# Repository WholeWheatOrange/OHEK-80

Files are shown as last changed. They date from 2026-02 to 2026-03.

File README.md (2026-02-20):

# OHEK-80
An analog hall effect keyboard using [Void Switches](https://github.com/riskable/void_switch) in the traditional 87-key tenkeyless layout.

# Roadmap
## Under Development
- PCB
## Planned Features
- Analog input
- Adjustable actuation point
- Rapid Trigger
- SOCD
- That Stupid Strap Attachment That Is A Trend In Hall Effect Keyboards

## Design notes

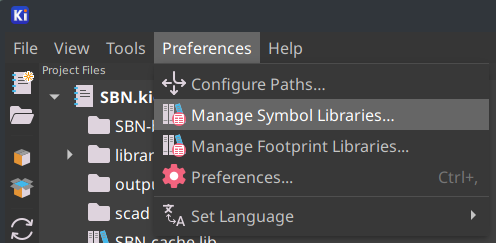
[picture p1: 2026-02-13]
kicad/void_switch_kicad/assets/images/prefs_symbols.png

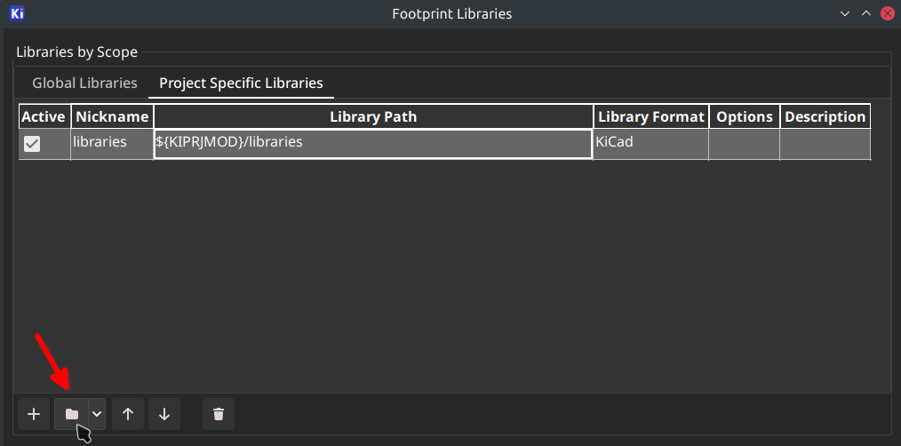
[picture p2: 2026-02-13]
kicad/void_switch_kicad/assets/images/add_footprint_path1.png

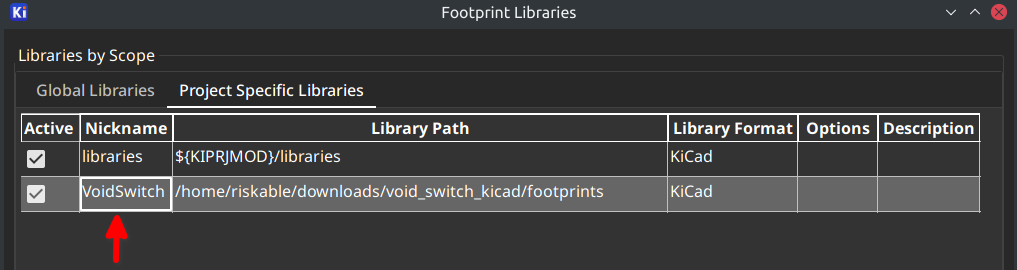
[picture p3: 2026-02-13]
kicad/void_switch_kicad/assets/images/add_footprint_path3.png

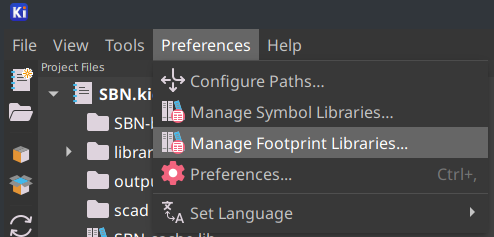
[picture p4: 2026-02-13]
kicad/void_switch_kicad/assets/images/prefs_footprints.png

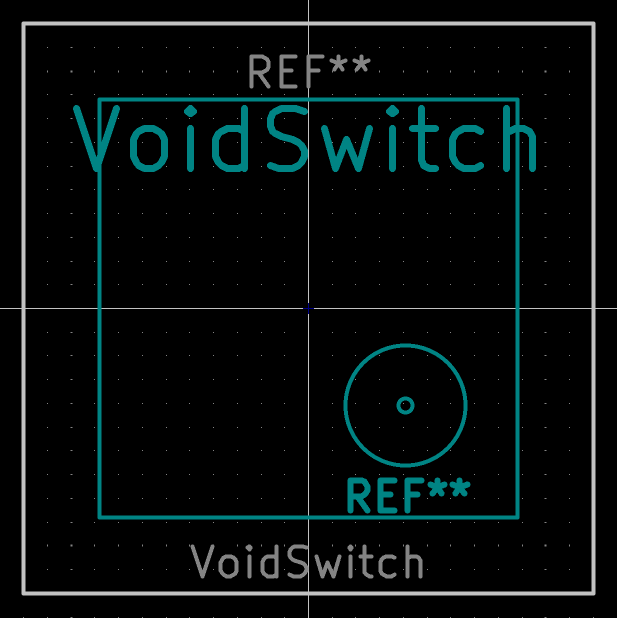
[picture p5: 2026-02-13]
kicad/void_switch_kicad/assets/images/voidswitch_footprint.png

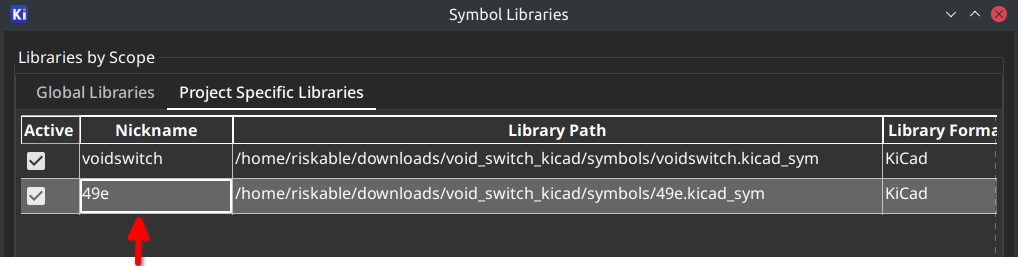
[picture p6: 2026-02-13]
kicad/void_switch_kicad/assets/images/add_symbols1.png

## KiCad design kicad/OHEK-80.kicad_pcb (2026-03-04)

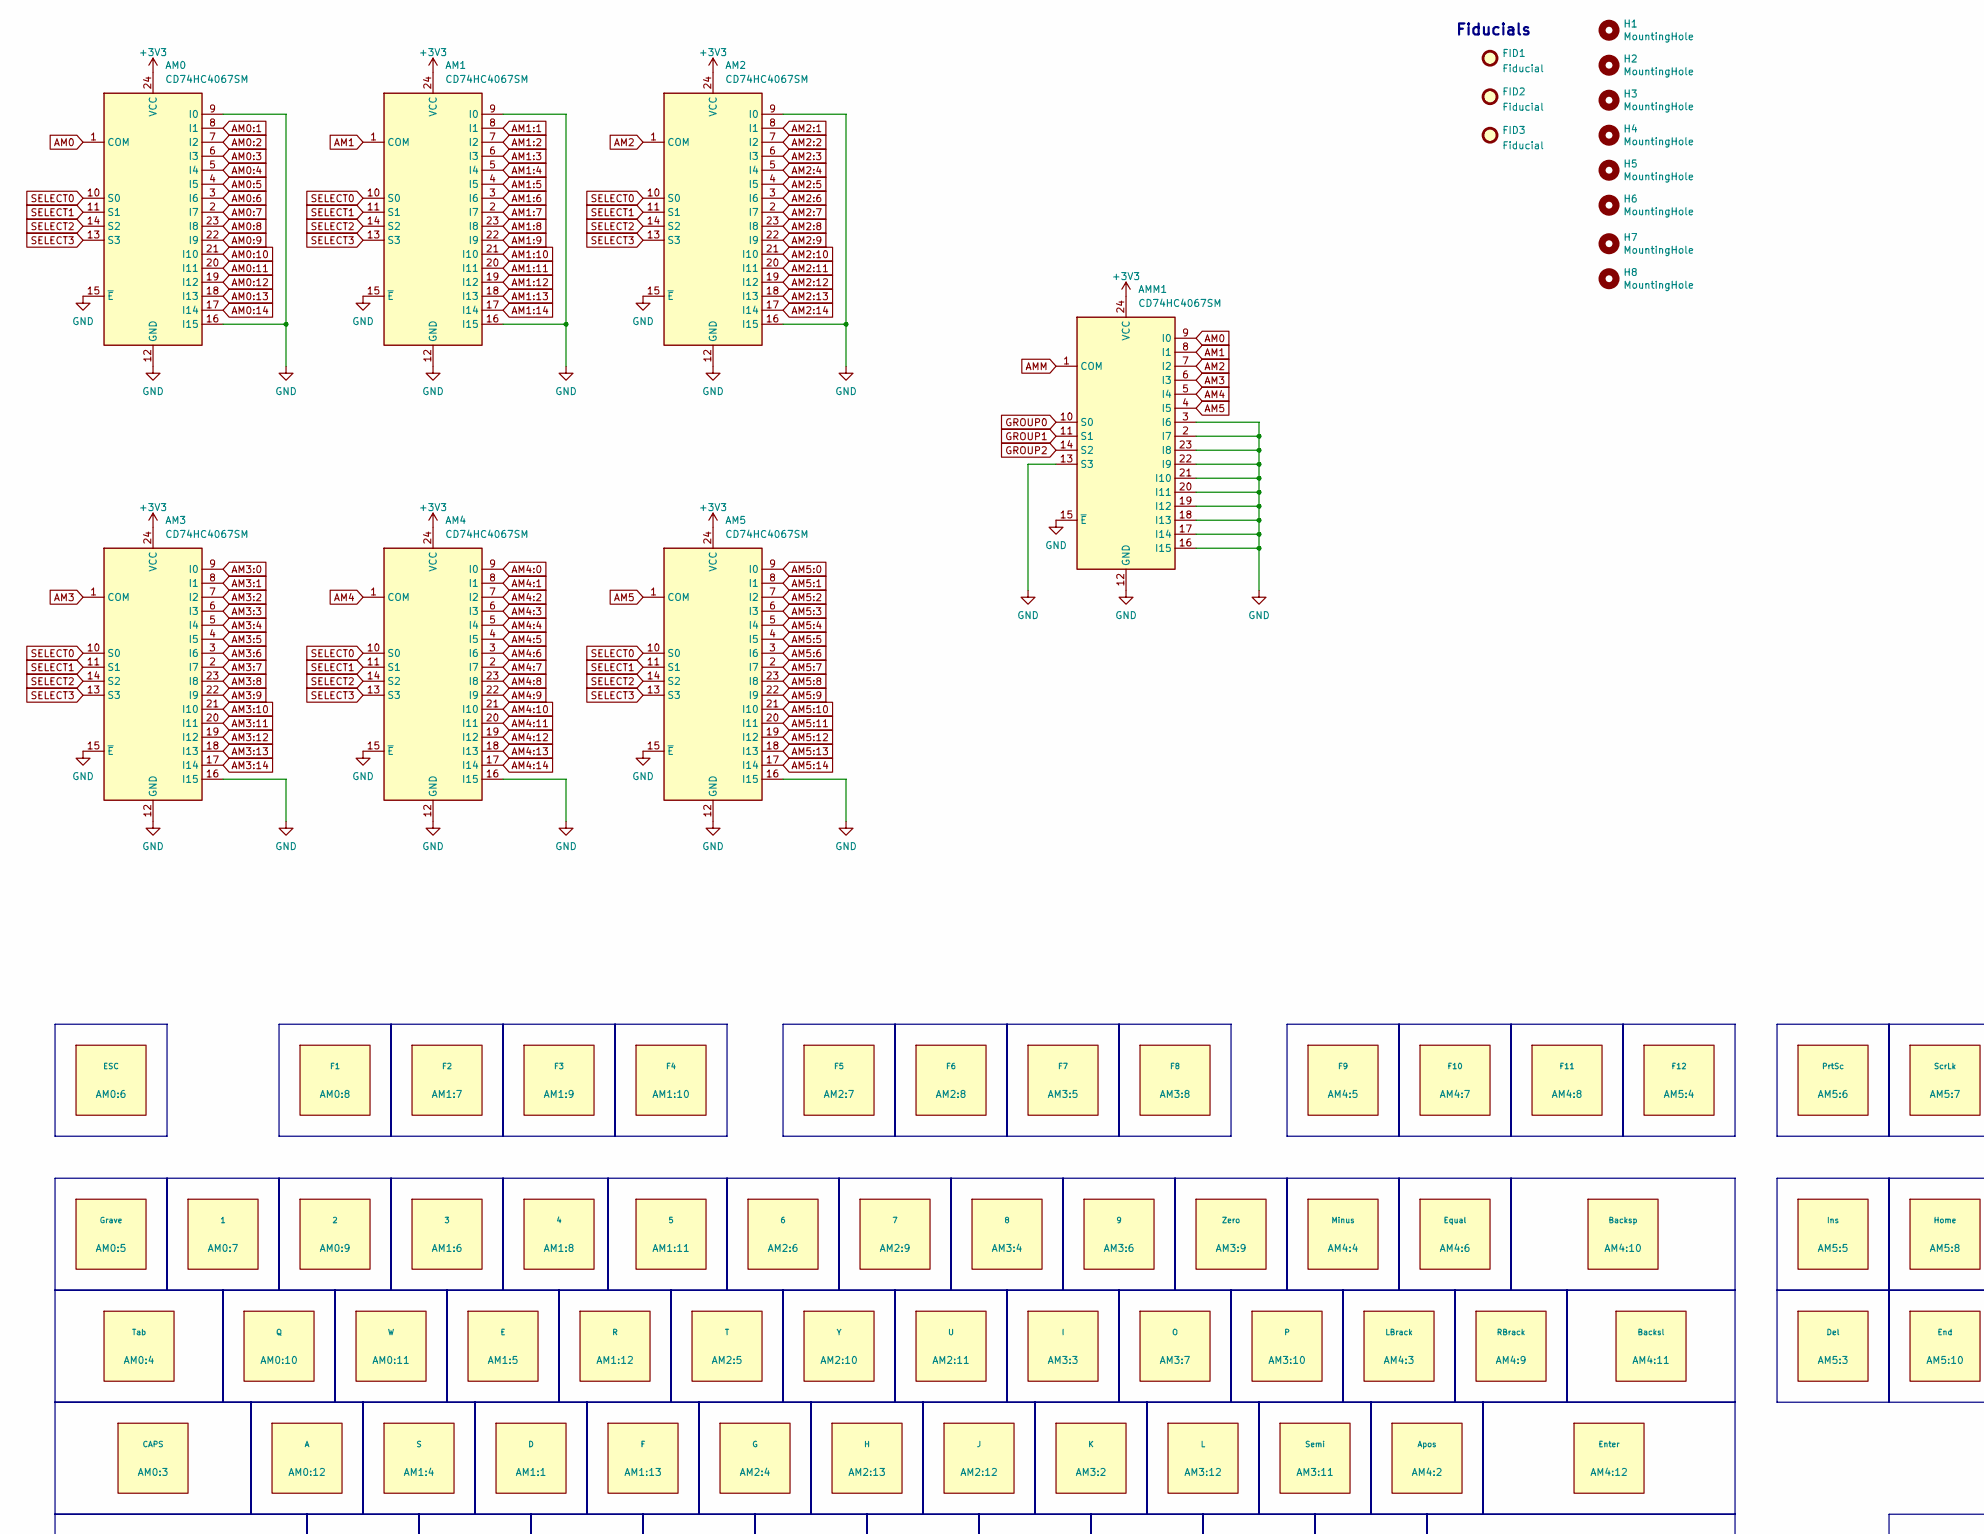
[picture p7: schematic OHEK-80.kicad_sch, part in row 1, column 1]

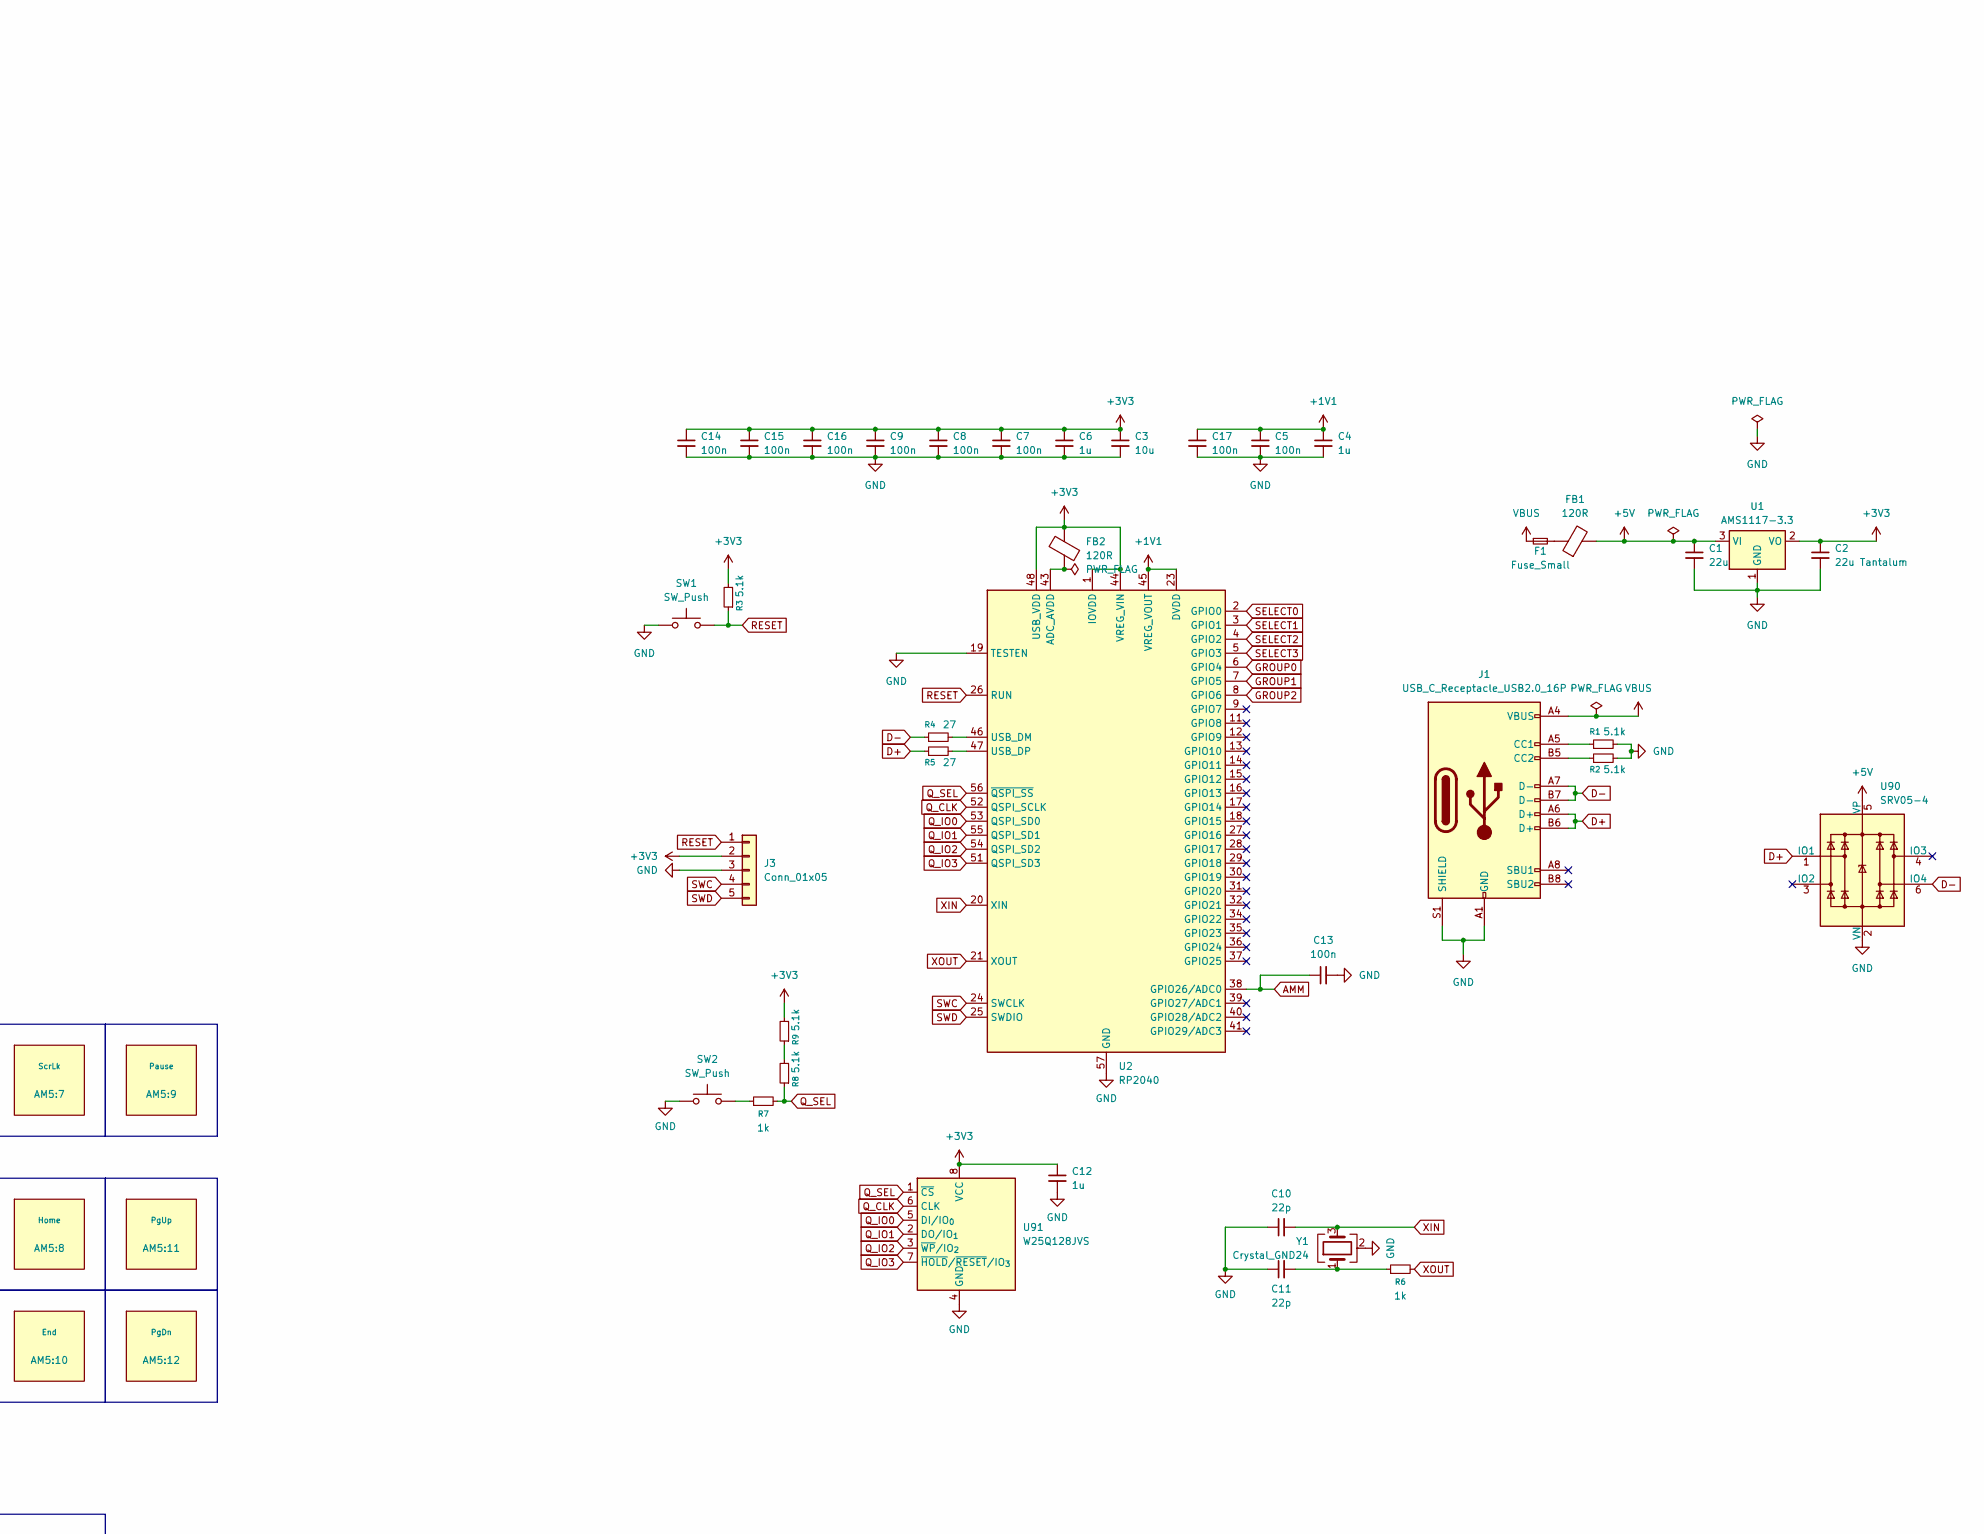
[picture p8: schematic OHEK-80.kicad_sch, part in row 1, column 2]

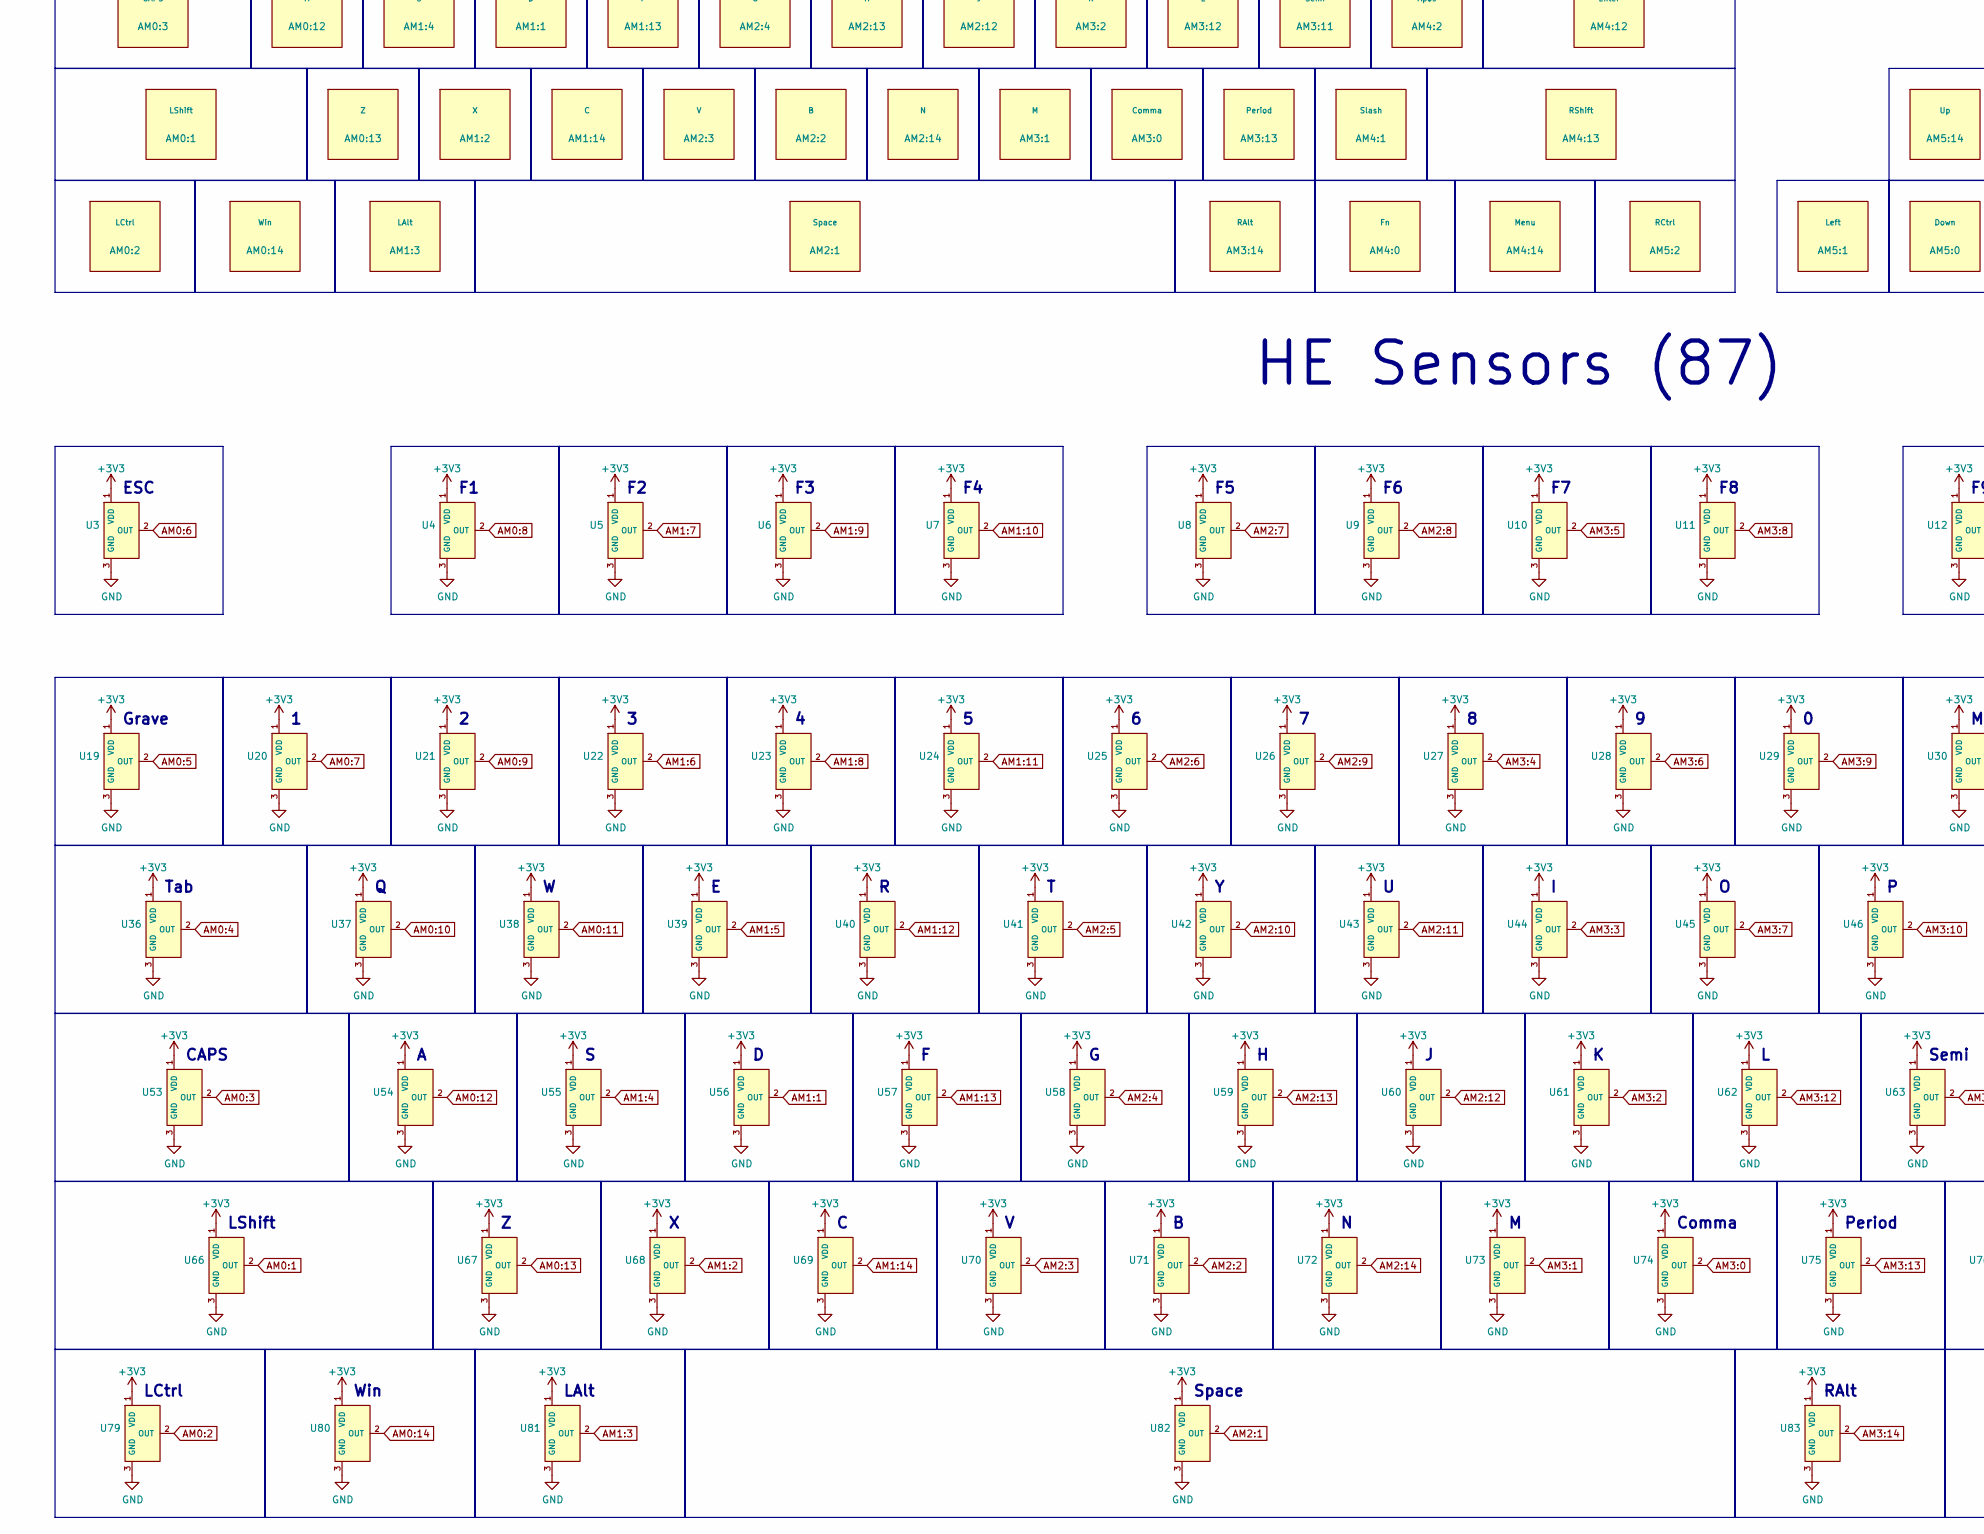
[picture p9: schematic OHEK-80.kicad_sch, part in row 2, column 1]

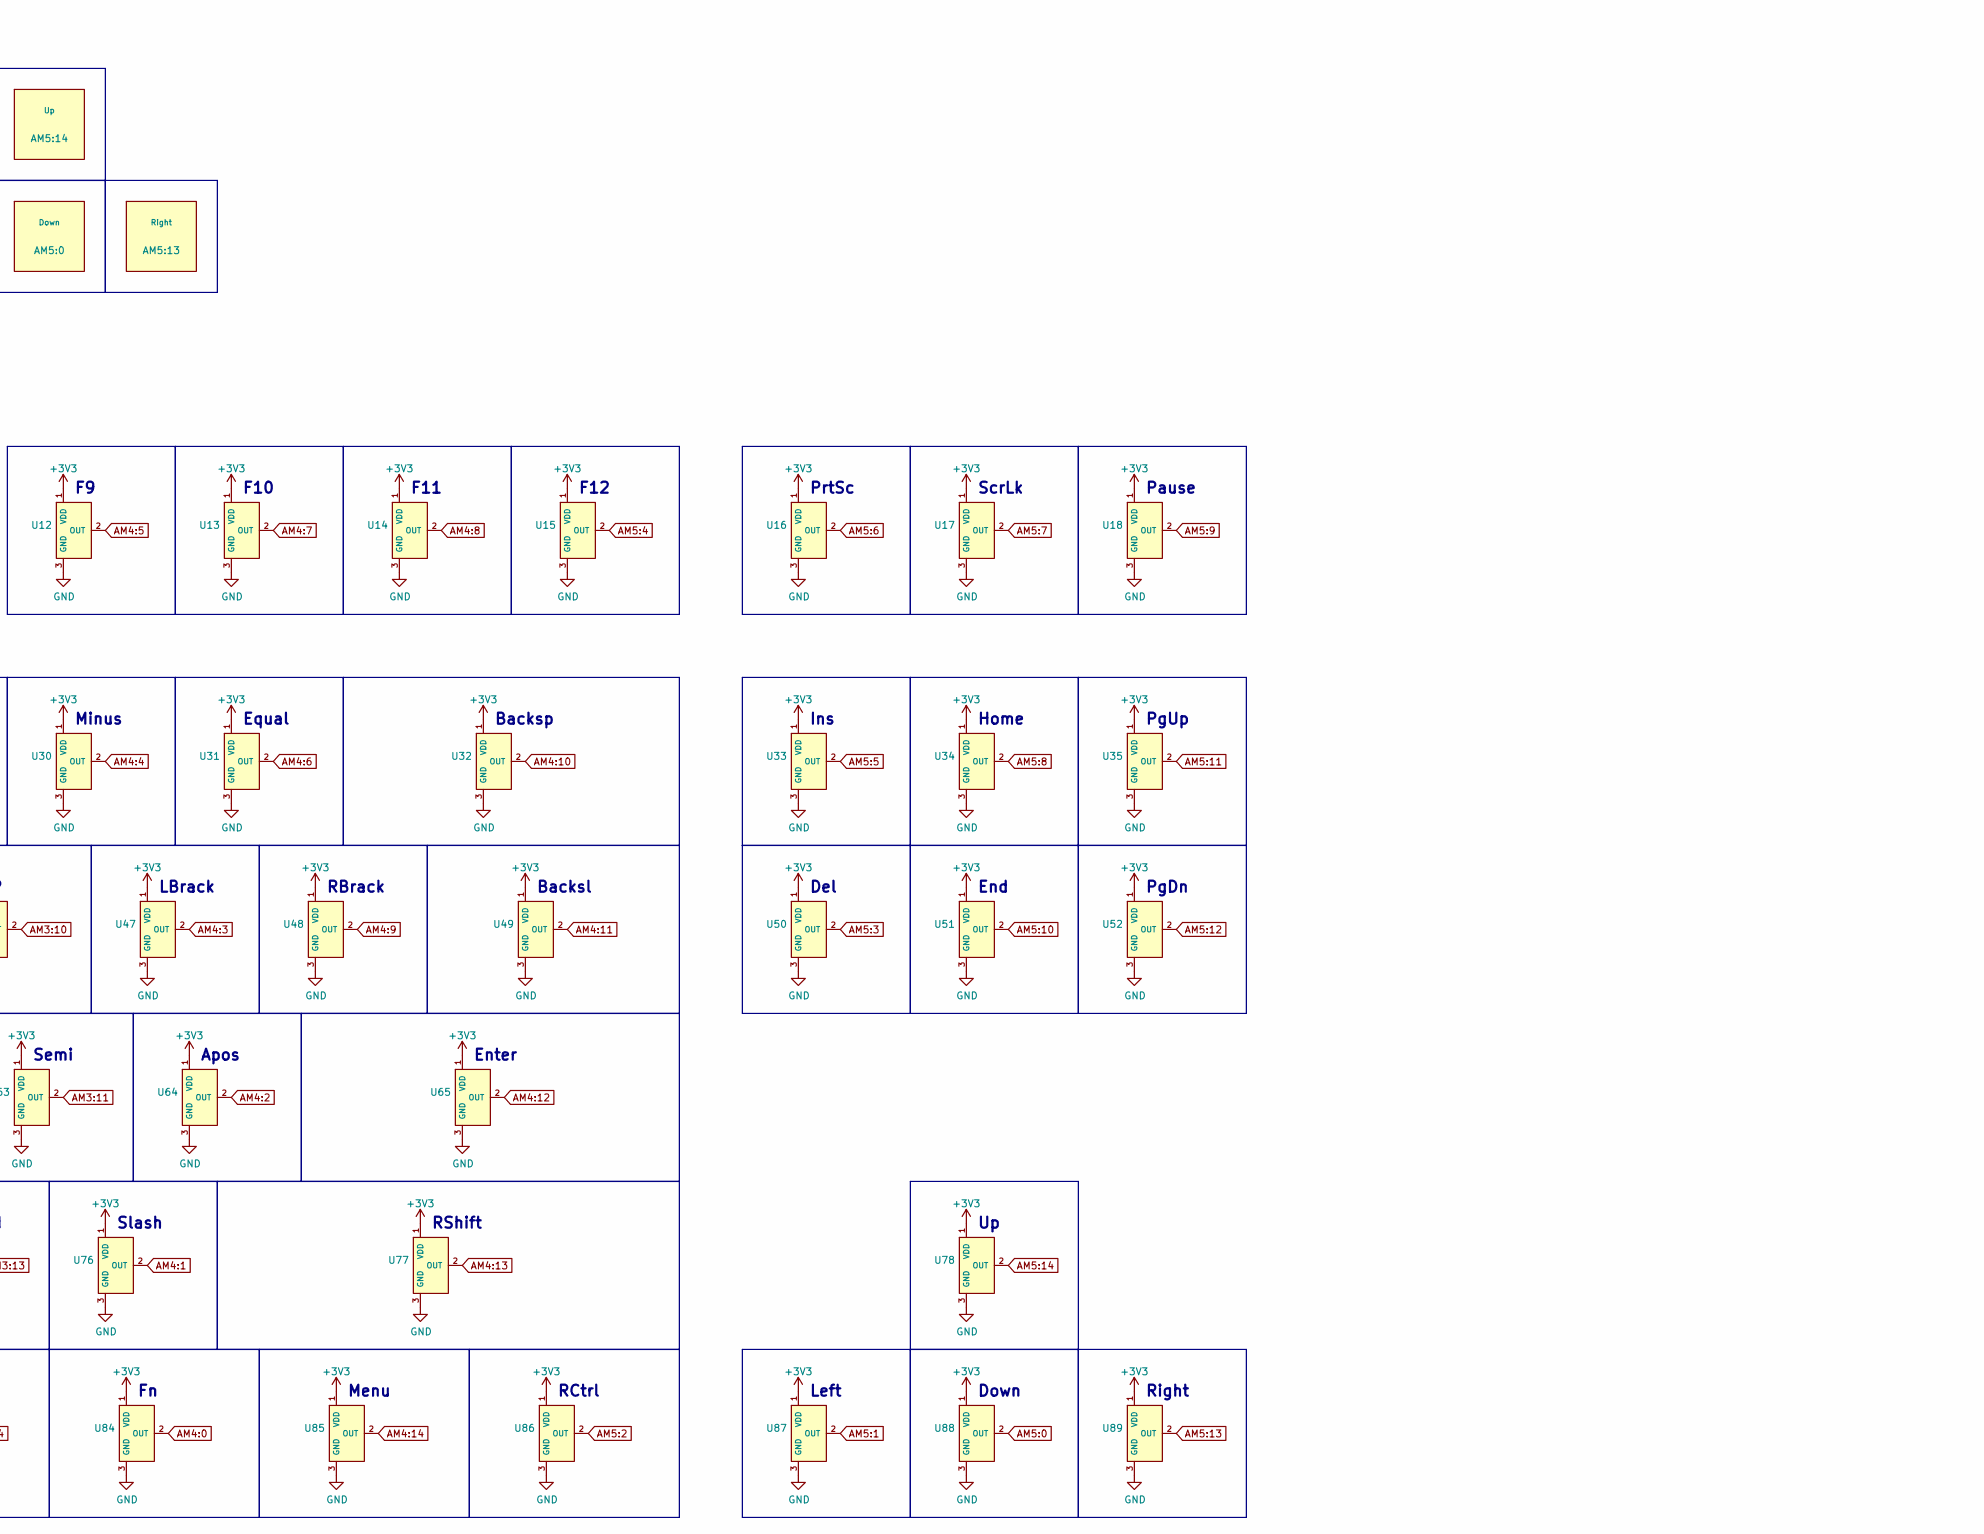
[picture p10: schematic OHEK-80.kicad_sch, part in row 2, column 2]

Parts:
AM0, AM1, AM2, AM3, AM4, AM5: CD74HC4067SM; SSOP-24_5.3x8.2mm_P0.65mm; LCSC C98457
AM0:1: LShift; VoidSwitch_2.25u_SMD
AM0:2: LCtrl; VoidSwitch_1.25u_SMD
AM0:3: CAPS; VoidSwitch_1.75u_SMD
AM0:4: Tab; VoidSwitch_1.5u_SMD
AM0:5: Grave; VoidSwitch_1u_SMD
AM0:6: ESC; VoidSwitch_1u_SMD
AM0:7: 1; VoidSwitch_1u_SMD
AM0:8: F1; VoidSwitch_1u_SMD
AM0:9: 2; VoidSwitch_1u_SMD
AM0:10: Q; VoidSwitch_1u_SMD
AM0:11: W; VoidSwitch_1u_SMD
AM0:12: A; VoidSwitch_1u_SMD
AM0:13: Z; VoidSwitch_1u_SMD
AM0:14: Win; VoidSwitch_1.25u_SMD
AM1:1: D; VoidSwitch_1u_SMD
AM1:2: X; VoidSwitch_1u_SMD
AM1:3: LAlt; VoidSwitch_1.25u_SMD
AM1:4: S; VoidSwitch_1u_SMD
AM1:5: E; VoidSwitch_1u_SMD
AM1:6: 3; VoidSwitch_1u_SMD
AM1:7: F2; VoidSwitch_1u_SMD
AM1:8: 4; VoidSwitch_1u_SMD
AM1:9: F3; VoidSwitch_1u_SMD
AM1:10: F4; VoidSwitch_1u_SMD
AM1:11: 5; VoidSwitch_1u_SMD
AM1:12: R; VoidSwitch_1u_SMD
AM1:13: F; VoidSwitch_1u_SMD
AM1:14: C; VoidSwitch_1u_SMD
AM2:1: Space; VoidSwitch_6.25u_SMD
AM2:2: B; VoidSwitch_1u_SMD
AM2:3: V; VoidSwitch_1u_SMD
AM2:4: G; VoidSwitch_1u_SMD
AM2:5: T; VoidSwitch_1u_SMD
AM2:6: 6; VoidSwitch_1u_SMD
AM2:7: F5; VoidSwitch_1u_SMD
AM2:8: F6; VoidSwitch_1u_SMD
AM2:9: 7; VoidSwitch_1u_SMD
AM2:10: Y; VoidSwitch_1u_SMD
AM2:11: U; VoidSwitch_1u_SMD
AM2:12: J; VoidSwitch_1u_SMD
AM2:13: H; VoidSwitch_1u_SMD
AM2:14: N; VoidSwitch_1u_SMD
AM3:0: Comma; VoidSwitch_1u_SMD
AM3:1: M; VoidSwitch_1u_SMD
AM3:2: K; VoidSwitch_1u_SMD
AM3:3: I; VoidSwitch_1u_SMD
AM3:4: 8; VoidSwitch_1u_SMD
AM3:5: F7; VoidSwitch_1u_SMD
AM3:6: 9; VoidSwitch_1u_SMD
AM3:7: O; VoidSwitch_1u_SMD
AM3:8: F8; VoidSwitch_1u_SMD
AM3:9: Zero; VoidSwitch_1u_SMD
AM3:10: P; VoidSwitch_1u_SMD
AM3:11: Semi; VoidSwitch_1u_SMD
AM3:12: L; VoidSwitch_1u_SMD
AM3:13: Period; VoidSwitch_1u_SMD
AM3:14: RAlt; VoidSwitch_1.25u_SMD
AM4:0: Fn; VoidSwitch_1.25u_SMD
AM4:1: Slash; VoidSwitch_1u_SMD
AM4:2: Apos; VoidSwitch_1u_SMD
AM4:3: LBrack; VoidSwitch_1u_SMD
AM4:4: Minus; VoidSwitch_1u_SMD
AM4:5: F9; VoidSwitch_1u_SMD
AM4:6: Equal; VoidSwitch_1u_SMD
AM4:7: F10; VoidSwitch_1u_SMD
AM4:8: F11; VoidSwitch_1u_SMD
AM4:9: RBrack; VoidSwitch_1u_SMD
AM4:10: Backsp; VoidSwitch_2u_SMD
AM4:11: Backsl; VoidSwitch_1.5u_SMD
AM4:12: Enter; VoidSwitch_2.25u_SMD
AM4:13: RShift; VoidSwitch_2.75u_SMD
AM4:14: Menu; VoidSwitch_1.25u_SMD
AM5:0: Down; VoidSwitch_1u_SMD
AM5:1: Left; VoidSwitch_1u_SMD
AM5:2: RCtrl; VoidSwitch_1.25u_SMD
AM5:3: Del; VoidSwitch_1u_SMD
AM5:4: F12; VoidSwitch_1u_SMD
AM5:5: Ins; VoidSwitch_1u_SMD
AM5:6: PrtSc; VoidSwitch_1u_SMD
AM5:7: ScrLk; VoidSwitch_1u_SMD
AM5:8: Home; VoidSwitch_1u_SMD
AM5:9: Pause; VoidSwitch_1u_SMD
AM5:10: End; VoidSwitch_1u_SMD
AM5:11: PgUp; VoidSwitch_1u_SMD
AM5:12: PgDn; VoidSwitch_1u_SMD
AM5:13: Right; VoidSwitch_1u_SMD
AM5:14: Up; VoidSwitch_1u_SMD
AMM1: CD74HC4067SM; SSOP-24_5.3x8.2mm_P0.65mm; LCSC C98457
C1: 22u; C_0805_2012Metric
C2: 22u Tantalum; C_0805_2012Metric; LCSC C1954754
C3: 10u; C_0805_2012Metric
C4, C6, C12: 1u; C_0805_2012Metric
C5, C7, C8, C9, C13, C14, C15, C16, C17: 100n; C_0805_2012Metric
C10, C11: 22p; C_0805_2012Metric
F1: Fuse_Small; Fuse_1206_3216Metric; LCSC C49318386
FB1, FB2: 120R; L_0805_2012Metric; LCSC C79382
FID1, FID2, FID3: Fiducial; Fiducial_1mm_Mask2mm
H1, H2, H3, H4, H5, H6, H7, H8: MountingHole; MountingHole_3.2mm_M3_Pad
J1: USB_C_Receptacle_USB2.0_16P; USB_C_Receptacle_HRO_TYPE-C-31-M-12; LCSC C165948
J3: Conn_01x05; JST_PH_S5B-PH-K_1x05_P2.00mm_Horizontal; LCSC C157923
R1, R2, R3, R8, R9: 5.1k; R_0805_2012Metric
R4, R5: 27; R_0805_2012Metric
R6, R7: 1k; R_0805_2012Metric
SW1, SW2: SW_Push; SW_SPST_TL3342; LCSC C318884
U1: AMS1117-3.3; SOT-223-3_TabPin2; LCSC C6186
U2: RP2040; QFN-56-1EP_7x7mm_P0.4mm_EP3.2x3.2mm; LCSC C2040
U3, U4, U5, U6, U7, U8, U9, U10, U11, U12, U13, U14, U15, U16, U17, U18, U19, U20, U21, U22, U23, U24, U25, U26, U27, U28, U29, U30, U31, U32, U33, U34, U35, U36, U37, U38, U39, U40, U41, U42, U43, U44, U45, U46, U47, U48, U49, U50, U51, U52, U53, U54, U55, U56, U57, U58, U59, U60, U61, U62, U63, U64, U65, U66, U67, U68, U69, U70, U71, U72, U73, U74, U75, U76, U77, U78, U79, U80, U81, U82, U83, U84, U85, U86, U87, U88, U89: GH39FKSW; SOT-23; MPN GH39FKSW; LCSC Part C266230
U90: SRV05-4; SOT-23-6; LCSC C7420376
U91: W25Q128JVS; SOIC-8_5.3x5.3mm_P1.27mm; LCSC C97521
Y1: Crystal_GND24; Crystal_SMD_3225-4Pin_3.2x2.5mm; LCSC C20625731

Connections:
+1V1: C4.1, C5.1, C17.1, U2.23 (DVDD), U2.45 (VREG_VOUT), U2.50 (DVDD)
+3V3: AM0.24 (VCC), AM1.24 (VCC), AM2.24 (VCC), AM3.24 (VCC), AM4.24 (VCC), AM5.24 (VCC), AMM1.24 (VCC), C2.1, C3.1, C6.1, C7.1, C8.1, C9.1, C12.1, C14.1, C15.1, C16.1, FB2.2, J3.2, R3.2, R9.2, U1.2 (VO), U2.1 (IOVDD), U2.10 (IOVDD), U2.22 (IOVDD), U2.33 (IOVDD), U2.42 (IOVDD), U2.44 (VREG_VIN), U2.48 (USB_VDD), U2.49 (IOVDD), U3.1 (VDD), U4.1 (VDD), U5.1 (VDD), U6.1 (VDD), U7.1 (VDD), U8.1 (VDD), U9.1 (VDD), U10.1 (VDD), U11.1 (VDD), U12.1 (VDD), U13.1 (VDD), U14.1 (VDD), U15.1 (VDD), U16.1 (VDD), U17.1 (VDD), U18.1 (VDD), U19.1 (VDD), U20.1 (VDD), U21.1 (VDD), U22.1 (VDD), U23.1 (VDD), U24.1 (VDD), U25.1 (VDD), U26.1 (VDD), U27.1 (VDD), U28.1 (VDD), U29.1 (VDD), U30.1 (VDD), U31.1 (VDD), U32.1 (VDD), U33.1 (VDD), U34.1 (VDD), U35.1 (VDD), U36.1 (VDD), U37.1 (VDD), U38.1 (VDD), U39.1 (VDD), U40.1 (VDD), U41.1 (VDD), U42.1 (VDD), U43.1 (VDD), U44.1 (VDD), U45.1 (VDD), U46.1 (VDD), U47.1 (VDD), U48.1 (VDD), U49.1 (VDD), U50.1 (VDD), U51.1 (VDD), U52.1 (VDD), U53.1 (VDD), U54.1 (VDD), U55.1 (VDD), U56.1 (VDD), U57.1 (VDD), U58.1 (VDD), U59.1 (VDD), U60.1 (VDD), U61.1 (VDD), U62.1 (VDD), U63.1 (VDD), U64.1 (VDD), U65.1 (VDD), U66.1 (VDD), U67.1 (VDD), U68.1 (VDD), U69.1 (VDD), U70.1 (VDD), U71.1 (VDD), U72.1 (VDD), U73.1 (VDD), U74.1 (VDD), U75.1 (VDD), U76.1 (VDD), U77.1 (VDD), U78.1 (VDD), U79.1 (VDD), U80.1 (VDD), U81.1 (VDD), U82.1 (VDD), U83.1 (VDD), U84.1 (VDD), U85.1 (VDD), U86.1 (VDD), U87.1 (VDD), U88.1 (VDD), U89.1 (VDD), U91.8 (VCC)
+5V: C1.1, FB1.2, U1.3 (VI), U90.5 (VP)
AM0: AM0.1 (COM), AMM1.9 (I0)
AM0:1: AM0.8 (I1), U66.2 (OUT)
AM0:2: AM0.7 (I2), U79.2 (OUT)
AM0:3: AM0.6 (I3), U53.2 (OUT)
AM0:4: AM0.5 (I4), U36.2 (OUT)
AM0:5: AM0.4 (I5), U19.2 (OUT)
AM0:6: AM0.3 (I6), U3.2 (OUT)
AM0:7: AM0.2 (I7), U20.2 (OUT)
AM0:8: AM0.23 (I8), U4.2 (OUT)
AM0:9: AM0.22 (I9), U21.2 (OUT)
AM0:10: AM0.21 (I10), U37.2 (OUT)
AM0:11: AM0.20 (I11), U38.2 (OUT)
AM0:12: AM0.19 (I12), U54.2 (OUT)
AM0:13: AM0.18 (I13), U67.2 (OUT)
AM0:14: AM0.17 (I14), U80.2 (OUT)
AM1: AM1.1 (COM), AMM1.8 (I1)
AM1:1: AM1.8 (I1), U56.2 (OUT)
AM1:2: AM1.7 (I2), U68.2 (OUT)
AM1:3: AM1.6 (I3), U81.2 (OUT)
AM1:4: AM1.5 (I4), U55.2 (OUT)
AM1:5: AM1.4 (I5), U39.2 (OUT)
AM1:6: AM1.3 (I6), U22.2 (OUT)
AM1:7: AM1.2 (I7), U5.2 (OUT)
AM1:8: AM1.23 (I8), U23.2 (OUT)
AM1:9: AM1.22 (I9), U6.2 (OUT)
AM1:10: AM1.21 (I10), U7.2 (OUT)
AM1:11: AM1.20 (I11), U24.2 (OUT)
AM1:12: AM1.19 (I12), U40.2 (OUT)
AM1:13: AM1.18 (I13), U57.2 (OUT)
AM1:14: AM1.17 (I14), U69.2 (OUT)
AM2: AM2.1 (COM), AMM1.7 (I2)
AM2:1: AM2.8 (I1), U82.2 (OUT)
AM2:2: AM2.7 (I2), U71.2 (OUT)
AM2:3: AM2.6 (I3), U70.2 (OUT)
AM2:4: AM2.5 (I4), U58.2 (OUT)
AM2:5: AM2.4 (I5), U41.2 (OUT)
AM2:6: AM2.3 (I6), U25.2 (OUT)
AM2:7: AM2.2 (I7), U8.2 (OUT)
AM2:8: AM2.23 (I8), U9.2 (OUT)
AM2:9: AM2.22 (I9), U26.2 (OUT)
AM2:10: AM2.21 (I10), U42.2 (OUT)
AM2:11: AM2.20 (I11), U43.2 (OUT)
AM2:12: AM2.19 (I12), U60.2 (OUT)
AM2:13: AM2.18 (I13), U59.2 (OUT)
AM2:14: AM2.17 (I14), U72.2 (OUT)
AM3: AM3.1 (COM), AMM1.6 (I3)
AM3:0: AM3.9 (I0), U74.2 (OUT)
AM3:1: AM3.8 (I1), U73.2 (OUT)
AM3:2: AM3.7 (I2), U61.2 (OUT)
AM3:3: AM3.6 (I3), U44.2 (OUT)
AM3:4: AM3.5 (I4), U27.2 (OUT)
AM3:5: AM3.4 (I5), U10.2 (OUT)
AM3:6: AM3.3 (I6), U28.2 (OUT)
AM3:7: AM3.2 (I7), U45.2 (OUT)
AM3:8: AM3.23 (I8), U11.2 (OUT)
AM3:9: AM3.22 (I9), U29.2 (OUT)
AM3:10: AM3.21 (I10), U46.2 (OUT)
AM3:11: AM3.20 (I11), U63.2 (OUT)
AM3:12: AM3.19 (I12), U62.2 (OUT)
AM3:13: AM3.18 (I13), U75.2 (OUT)
AM3:14: AM3.17 (I14), U83.2 (OUT)
AM4: AM4.1 (COM), AMM1.5 (I4)
AM4:0: AM4.9 (I0), U84.2 (OUT)
AM4:1: AM4.8 (I1), U76.2 (OUT)
AM4:2: AM4.7 (I2), U64.2 (OUT)
AM4:3: AM4.6 (I3), U47.2 (OUT)
AM4:4: AM4.5 (I4), U30.2 (OUT)
AM4:5: AM4.4 (I5), U12.2 (OUT)
AM4:6: AM4.3 (I6), U31.2 (OUT)
AM4:7: AM4.2 (I7), U13.2 (OUT)
AM4:8: AM4.23 (I8), U14.2 (OUT)
AM4:9: AM4.22 (I9), U48.2 (OUT)
AM4:10: AM4.21 (I10), U32.2 (OUT)
AM4:11: AM4.20 (I11), U49.2 (OUT)
AM4:12: AM4.19 (I12), U65.2 (OUT)
AM4:13: AM4.18 (I13), U77.2 (OUT)
AM4:14: AM4.17 (I14), U85.2 (OUT)
AM5: AM5.1 (COM), AMM1.4 (I5)
AM5:0: AM5.9 (I0), U88.2 (OUT)
AM5:1: AM5.8 (I1), U87.2 (OUT)
AM5:2: AM5.7 (I2), U86.2 (OUT)
AM5:3: AM5.6 (I3), U50.2 (OUT)
AM5:4: AM5.5 (I4), U15.2 (OUT)
AM5:5: AM5.4 (I5), U33.2 (OUT)
AM5:6: AM5.3 (I6), U16.2 (OUT)
AM5:7: AM5.2 (I7), U17.2 (OUT)
AM5:8: AM5.23 (I8), U34.2 (OUT)
AM5:9: AM5.22 (I9), U18.2 (OUT)
AM5:10: AM5.21 (I10), U51.2 (OUT)
AM5:11: AM5.20 (I11), U35.2 (OUT)
AM5:12: AM5.19 (I12), U52.2 (OUT)
AM5:13: AM5.18 (I13), U89.2 (OUT)
AM5:14: AM5.17 (I14), U78.2 (OUT)
AMM: AMM1.1 (COM), C13.1, U2.38 (GPIO26/ADC0)
D+: J1.A6 (D+), J1.B6 (D+), R5.1, U90.1 (IO1)
D-: J1.A7 (D-), J1.B7 (D-), R4.1, U90.6 (IO4)
GND: AM0.9 (I0), AM0.12 (GND), AM0.15 (~E), AM0.16 (I15), AM1.9 (I0), AM1.12 (GND), AM1.15 (~E), AM1.16 (I15), AM2.9 (I0), AM2.12 (GND), AM2.15 (~E), AM2.16 (I15), AM3.12 (GND), AM3.15 (~E), AM3.16 (I15), AM4.12 (GND), AM4.15 (~E), AM4.16 (I15), AM5.12 (GND), AM5.15 (~E), AM5.16 (I15), AMM1.2 (I7), AMM1.3 (I6), AMM1.12 (GND), AMM1.13 (S3), AMM1.15 (~E), AMM1.16 (I15), AMM1.17 (I14), AMM1.18 (I13), AMM1.19 (I12), AMM1.20 (I11), AMM1.21 (I10), AMM1.22 (I9), AMM1.23 (I8), C1.2, C2.2, C3.2, C4.2, C5.2, C6.2, C7.2, C8.2, C9.2, C10.1, C11.1, C12.2, C13.2, C14.2, C15.2, C16.2, C17.2, J1.A1 (GND), J1.A12 (GND), J1.B1 (GND), J1.B12 (GND), J1.S1 (SHIELD), J3.3, R1.2, R2.2, SW1.1, SW2.1, U1.1 (GND), U2.19 (TESTEN), U2.57 (GND), U3.3 (GND), U4.3 (GND), U5.3 (GND), U6.3 (GND), U7.3 (GND), U8.3 (GND), U9.3 (GND), U10.3 (GND), U11.3 (GND), U12.3 (GND), U13.3 (GND), U14.3 (GND), U15.3 (GND), U16.3 (GND), U17.3 (GND), U18.3 (GND), U19.3 (GND), U20.3 (GND), U21.3 (GND), U22.3 (GND), U23.3 (GND), U24.3 (GND), U25.3 (GND), U26.3 (GND), U27.3 (GND), U28.3 (GND), U29.3 (GND), U30.3 (GND), U31.3 (GND), U32.3 (GND), U33.3 (GND), U34.3 (GND), U35.3 (GND), U36.3 (GND), U37.3 (GND), U38.3 (GND), U39.3 (GND), U40.3 (GND), U41.3 (GND), U42.3 (GND), U43.3 (GND), U44.3 (GND), U45.3 (GND), U46.3 (GND), U47.3 (GND), U48.3 (GND), U49.3 (GND), U50.3 (GND), U51.3 (GND), U52.3 (GND), U53.3 (GND), U54.3 (GND), U55.3 (GND), U56.3 (GND), U57.3 (GND), U58.3 (GND), U59.3 (GND), U60.3 (GND), U61.3 (GND), U62.3 (GND), U63.3 (GND), U64.3 (GND), U65.3 (GND), U66.3 (GND), U67.3 (GND), U68.3 (GND), U69.3 (GND), U70.3 (GND), U71.3 (GND), U72.3 (GND), U73.3 (GND), U74.3 (GND), U75.3 (GND), U76.3 (GND), U77.3 (GND), U78.3 (GND), U79.3 (GND), U80.3 (GND), U81.3 (GND), U82.3 (GND), U83.3 (GND), U84.3 (GND), U85.3 (GND), U86.3 (GND), U87.3 (GND), U88.3 (GND), U89.3 (GND), U90.2 (VN), U91.4 (GND), Y1.2 (G), Y1.4 (G)
GROUP0: AMM1.10 (S0), U2.6 (GPIO4)
GROUP1: AMM1.11 (S1), U2.7 (GPIO5)
GROUP2: AMM1.14 (S2), U2.8 (GPIO6)
unnamed: C11.2, R6.1, Y1.1
unnamed: F1.2, FB1.1
unnamed: J1.A5 (CC1), R1.1
unnamed: J1.B5 (CC2), R2.1
unnamed: R7.1, SW2.2
unnamed: R8.2, R9.1
unnamed: FB2.1, U2.43 (ADC_AVDD)
unnamed: R4.2, U2.46 (USB_DM)
unnamed: R5.2, U2.47 (USB_DP)
Q_CLK: U2.52 (QSPI_SCLK), U91.6 (CLK)
Q_IO0: U2.53 (QSPI_SD0), U91.5 (DI/IO_{0})
Q_IO1: U2.55 (QSPI_SD1), U91.2 (DO/IO_{1})
Q_IO2: U2.54 (QSPI_SD2), U91.3 (~WP/IO_{2})
Q_IO3: U2.51 (QSPI_SD3), U91.7 (~HOLD/~RESET/IO_{3})
Q_SEL: R7.2, R8.1, U2.56 (~QSPI_SS), U91.1 (~CS)
RESET: J3.1, R3.1, SW1.2, U2.26 (RUN)
SELECT0: AM0.10 (S0), AM1.10 (S0), AM2.10 (S0), AM3.10 (S0), AM4.10 (S0), AM5.10 (S0), U2.2 (GPIO0)
SELECT1: AM0.11 (S1), AM1.11 (S1), AM2.11 (S1), AM3.11 (S1), AM4.11 (S1), AM5.11 (S1), U2.3 (GPIO1)
SELECT2: AM0.14 (S2), AM1.14 (S2), AM2.14 (S2), AM3.14 (S2), AM4.14 (S2), AM5.14 (S2), U2.4 (GPIO2)
SELECT3: AM0.13 (S3), AM1.13 (S3), AM2.13 (S3), AM3.13 (S3), AM4.13 (S3), AM5.13 (S3), U2.5 (GPIO3)
SWC: J3.4, U2.24 (SWCLK)
SWD: J3.5, U2.25 (SWDIO)
VBUS: F1.1, J1.A4 (VBUS), J1.A9 (VBUS), J1.B4 (VBUS), J1.B9 (VBUS)
XIN: C10.2, U2.20 (XIN), Y1.3
XOUT: R6.2, U2.21 (XOUT)

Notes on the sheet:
Home
RAlt
PgUp
End
ScrLk
Right
RBrack
Del
Slash
Backsp
LAlt
Ins
Enter
Semi
Left
LCtrl
F10
Grave
Equal
PrtSc
Down
HE Sensors (87)
Menu
Comma
Space
Tab
Pause
CAPS
RCtrl
F12
Apos
F11
Backsl
Period
LShift
LBrack
Minus
Fiducials
ESC
PgDn

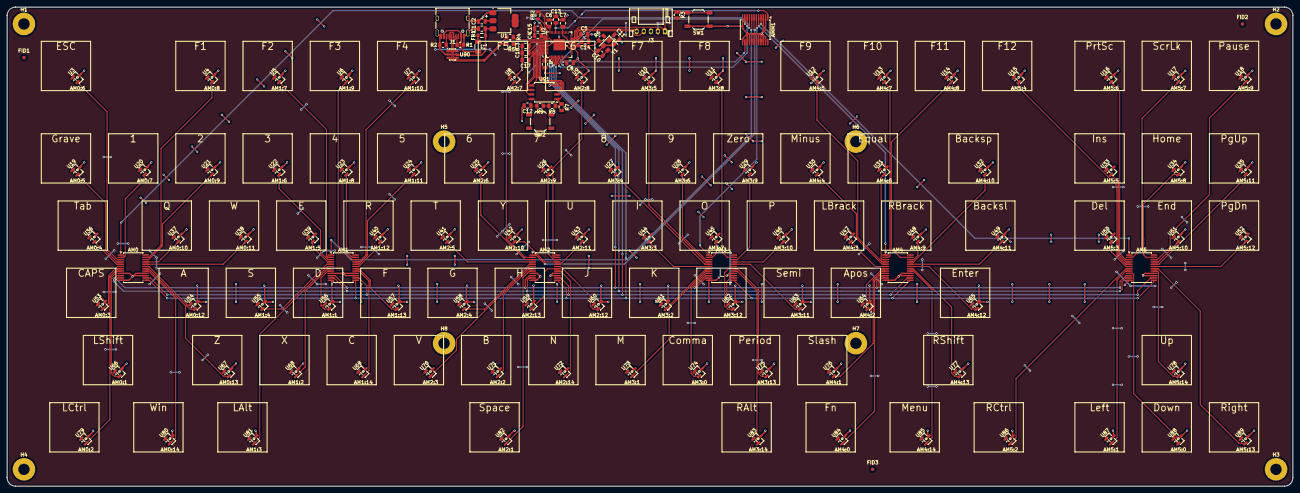
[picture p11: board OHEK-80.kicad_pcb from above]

Board: 2 copper layers, 364.3 x 135.7 mm, 230 parts (0 on the bottom side), 128 nets.

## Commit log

2026-02-13 Add kicad folder
    [OHEK-80.kicad_pcb, OHEK-80.kicad_sch]
2026-02-20 Removed J2 and cleaned up PCB a bit
    I realized that daughterboard support is useless as Void Switches are entirely contactless so there is no use in gasket mounting the keyboard.
    [OHEK-80.kicad_pcb, OHEK-80.kicad_sch]
2026-02-22 Fix issue where FB1 and F1 were in parallel
    [OHEK-80.kicad_pcb, OHEK-80.kicad_sch]
2026-03-04 Fix incorrect footprints for SW1 and SW2
    [OHEK-80.kicad_pcb, OHEK-80.kicad_sch]
